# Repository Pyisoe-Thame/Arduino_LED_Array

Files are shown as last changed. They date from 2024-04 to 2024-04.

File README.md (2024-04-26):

# 8x24 LED Array, Atmega328PB

This is my PCB Design practice project. ATmega328PB is the upgraded version of ATmega328P which is no longer recommeded for new design at this time. Instead Atmega328PB is in production of microchip with more or less the same price. The distinct feature of this MCU that I noticed is it has an extra SPI protocol and some expansion on memories.

The circuit 4 74595A shift registers; one for 8 LED rows and the others for the columns.
In the circuit I used all four 595 chips have the same CLK pin connect together and 3 of them are daisy-chained to shift a total of 24 columns, the rest one is used for columns each pin cooperated
by a PNP transistor.

While it may not be able to give HIGH to all the LEDs at once, you can use time division multiplexing to achieve the same visual effect by lighting each led at multiple time slots at high frequency.

## Features

- Arudino compatible Atmega328PB-AU
- DC Jack to 5V AMS1117
- Programming with ICSP
- 74HC595A shift registers
- 24 columns, 8 rows of output LEDs

## Screenshots

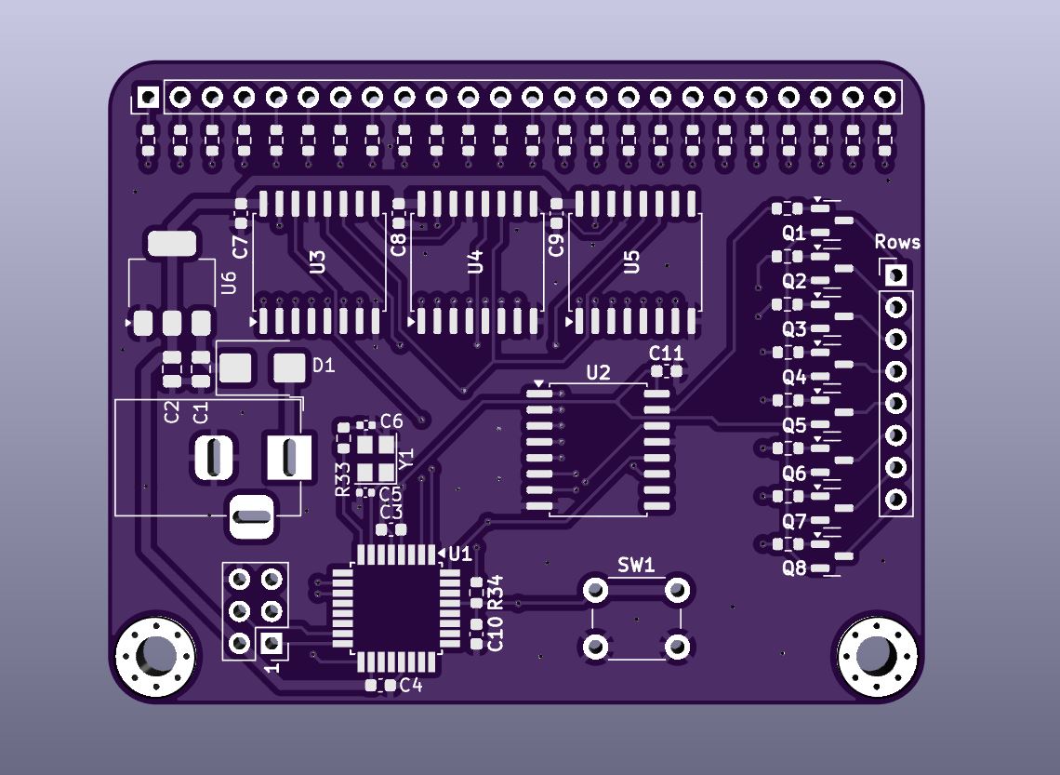
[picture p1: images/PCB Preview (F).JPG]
Front View

<p align="center">Front View</p>

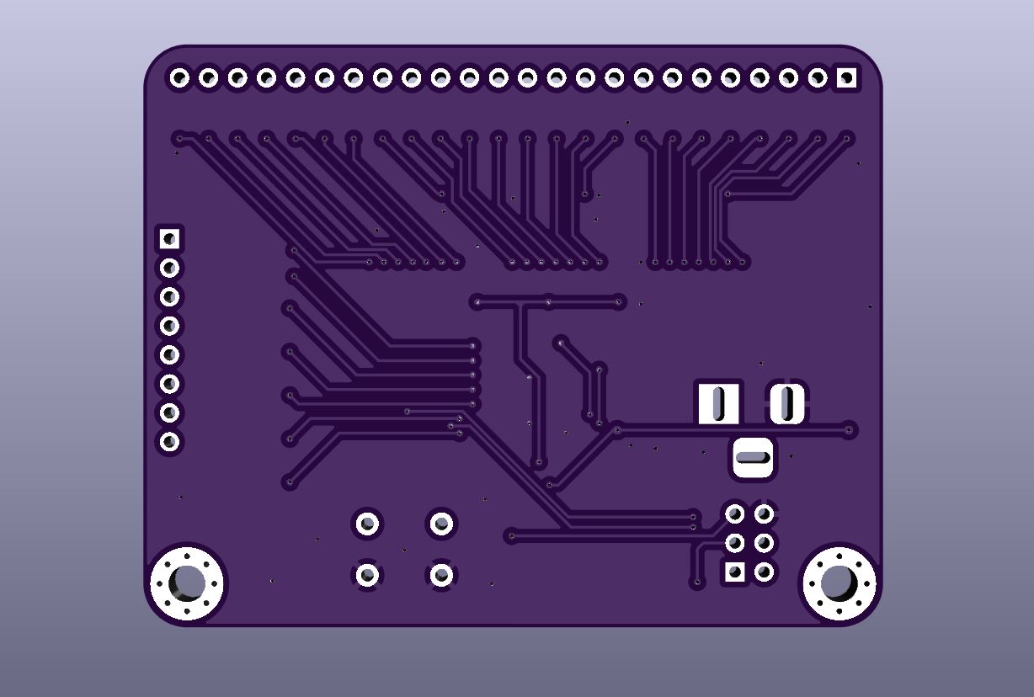
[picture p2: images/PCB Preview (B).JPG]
Back View

<p align="center">Back View</p>

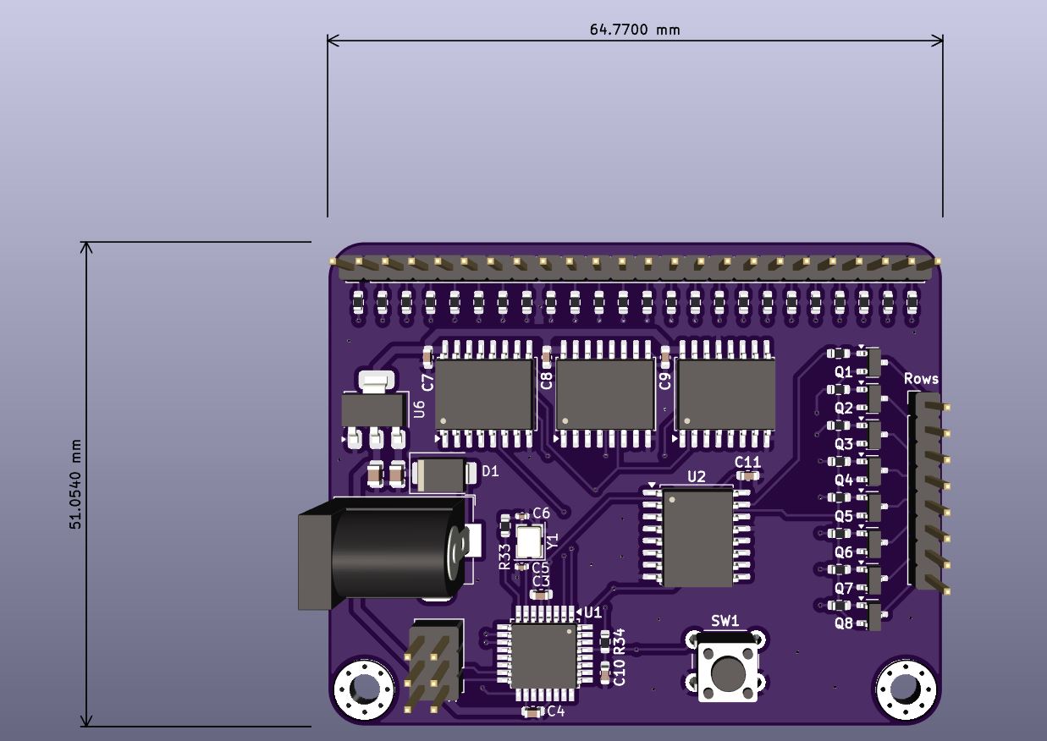
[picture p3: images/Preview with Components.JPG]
Preview with Components

<p align="center">Preview with Components</p>

## License

[MIT](https://choosealicense.com/licenses/mit/)

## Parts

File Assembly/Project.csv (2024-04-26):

Reference | Value | Datasheet | Footprint | Qty | DNP
C1,C2 | 10uF | ~ | Capacitor_SMD:C_0805_2012Metric | 2
C3,C4,C7,C8,C9,C10,C11 | 100nF | ~ | Capacitor_SMD:C_0603_1608Metric | 7
C5,C6 | 22p | ~ | Capacitor_SMD:C_0402_1005Metric | 2
D1 | M7 | https://www.tme.eu/Document/0550e9bf27627c5cdfb653945cb570ca/m1-m7.pdf | Diode_SMD:D_SMB | 1
H1,H2 | MountingHole_Pad | ~ | MountingHole:MountingHole_3.2mm_M3_Pad_Via | 2
J1 | DC Jack | ~ | Connector_BarrelJack:BarrelJack_Horizontal | 1
J2 | LED_Cols | ~ | Connector_PinHeader_2.54mm:PinHeader_1x24_P2.54mm_Vertical | 1
J3 | LED_Rows | ~ | Connector_PinHeader_2.54mm:PinHeader_1x08_P2.54mm_Vertical | 1
J4 | ICSP_Connector |  | Connector_PinHeader_2.54mm:PinHeader_2x03_P2.54mm_Vertical | 1
Q1,Q2,Q3,Q4,Q5,Q6,Q7,Q8 | BC857 | https://www.onsemi.com/pub/Collateral/BC860-D.pdf | Package_TO_SOT_SMD:SOT-23 | 8
R1,R2,R3,R4,R5,R6,R7,R8,R9,R10,R11,R12,R13,R14,R15,R16,R17,R18,R19,R20,R21,R22,R23,R24 | 220R | ~ | Resistor_SMD:R_0603_1608Metric | 24
R25,R26,R27,R28,R29,R30,R31,R32 | 100R | ~ | Resistor_SMD:R_0603_1608Metric | 8
R33 | 47R | ~ | Resistor_SMD:R_0603_1608Metric | 1
R34 | 10k | ~ | Resistor_SMD:R_0603_1608Metric | 1
SW1 | PB_6mm |  | Button_Switch_THT:SW_PUSH_6mm | 1
U1 | ATmega328PB-AU | http://ww1.microchip.com/downloads/en/DeviceDoc/40001906C.pdf | Package_QFP:TQFP-32_7x7mm_P0.8mm | 1
U2,U3,U4,U5 | 74HC595 | http://www.ti.com/lit/ds/symlink/sn74hc595.pdf | Package_SO:SOIC-16W_7.5x10.3mm_P1.27mm | 4
U6 | AMS1117-5.0 | http://www.advanced-monolithic.com/pdf/ds1117.pdf | Package_TO_SOT_SMD:SOT-223-3_TabPin2 | 1
Y1 | 16MHz | ~ | Crystal:Crystal_SMD_3225-4Pin_3.2x2.5mm | 1

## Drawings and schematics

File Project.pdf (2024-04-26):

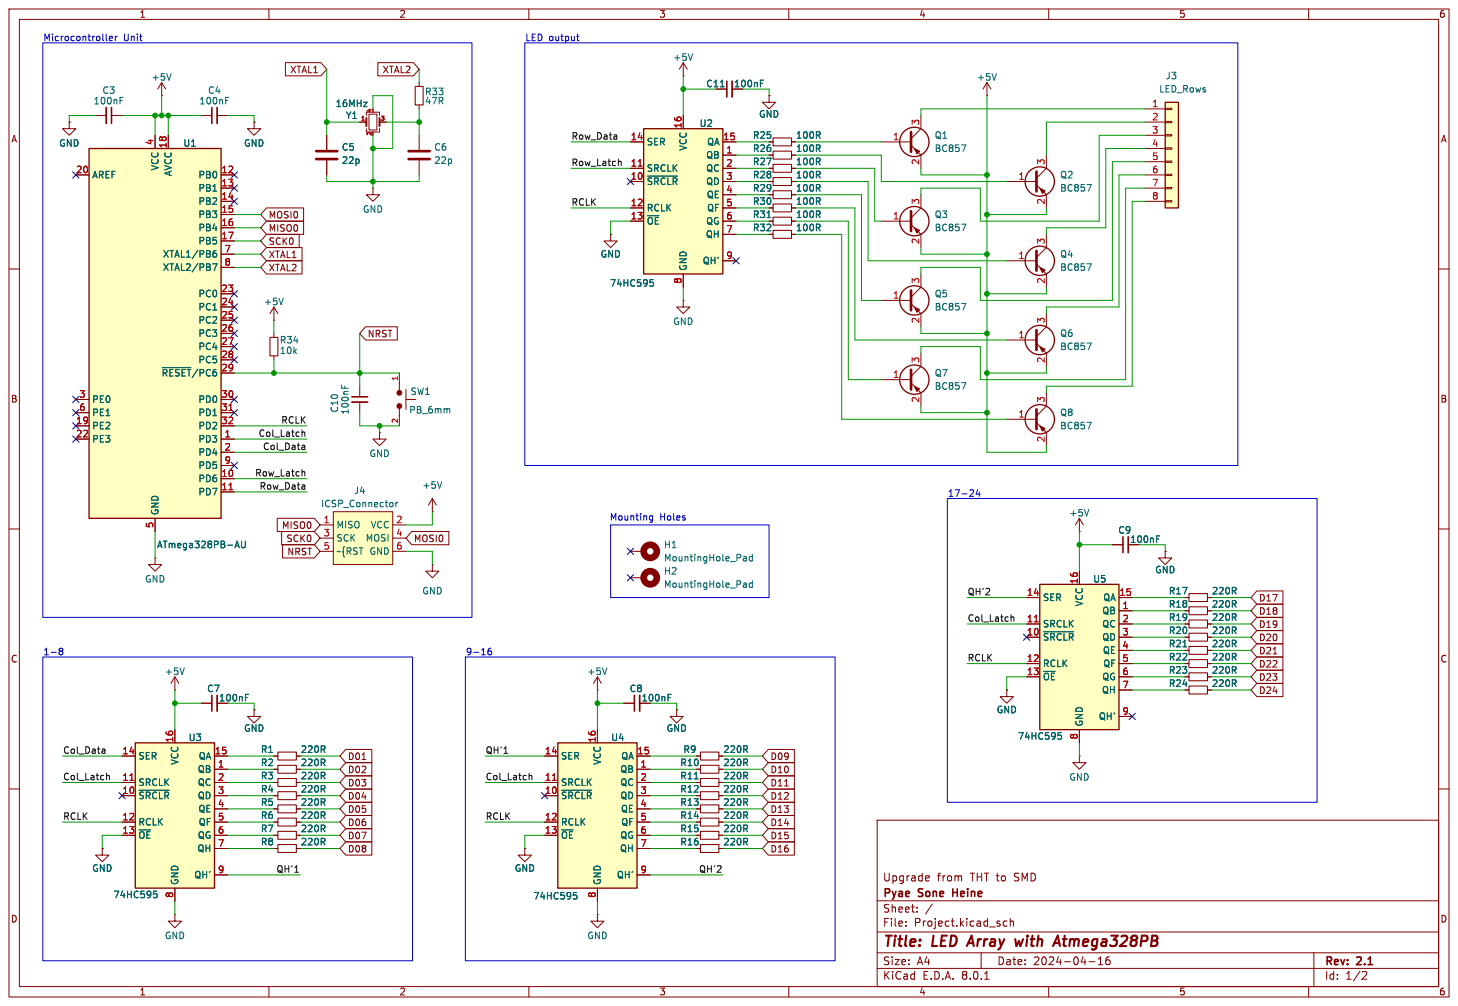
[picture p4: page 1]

Id: 1/2 Title: LED Array with Atmega328PB

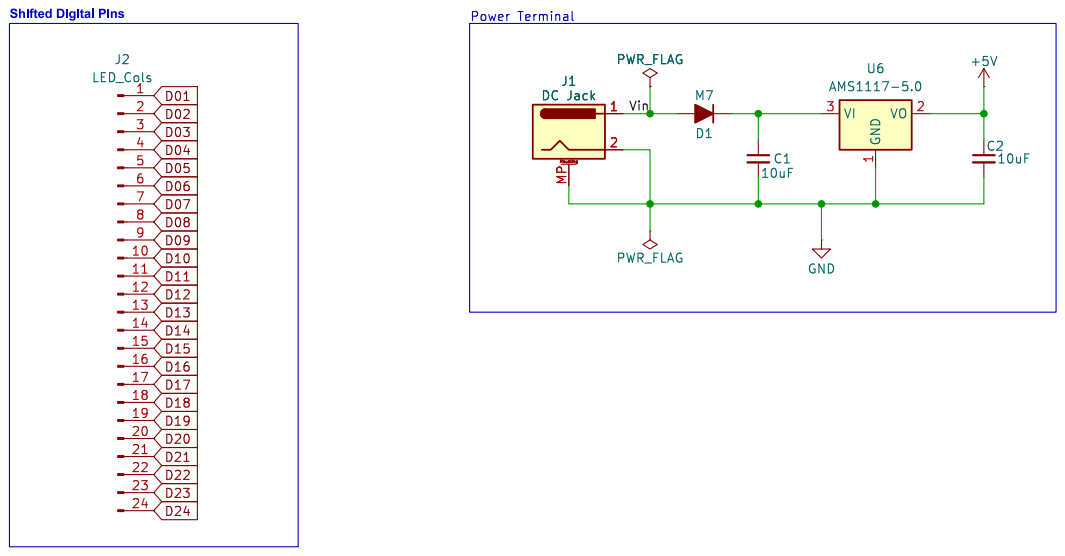
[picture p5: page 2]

Id: 2/2 Title: LED Array with Atmega328PB

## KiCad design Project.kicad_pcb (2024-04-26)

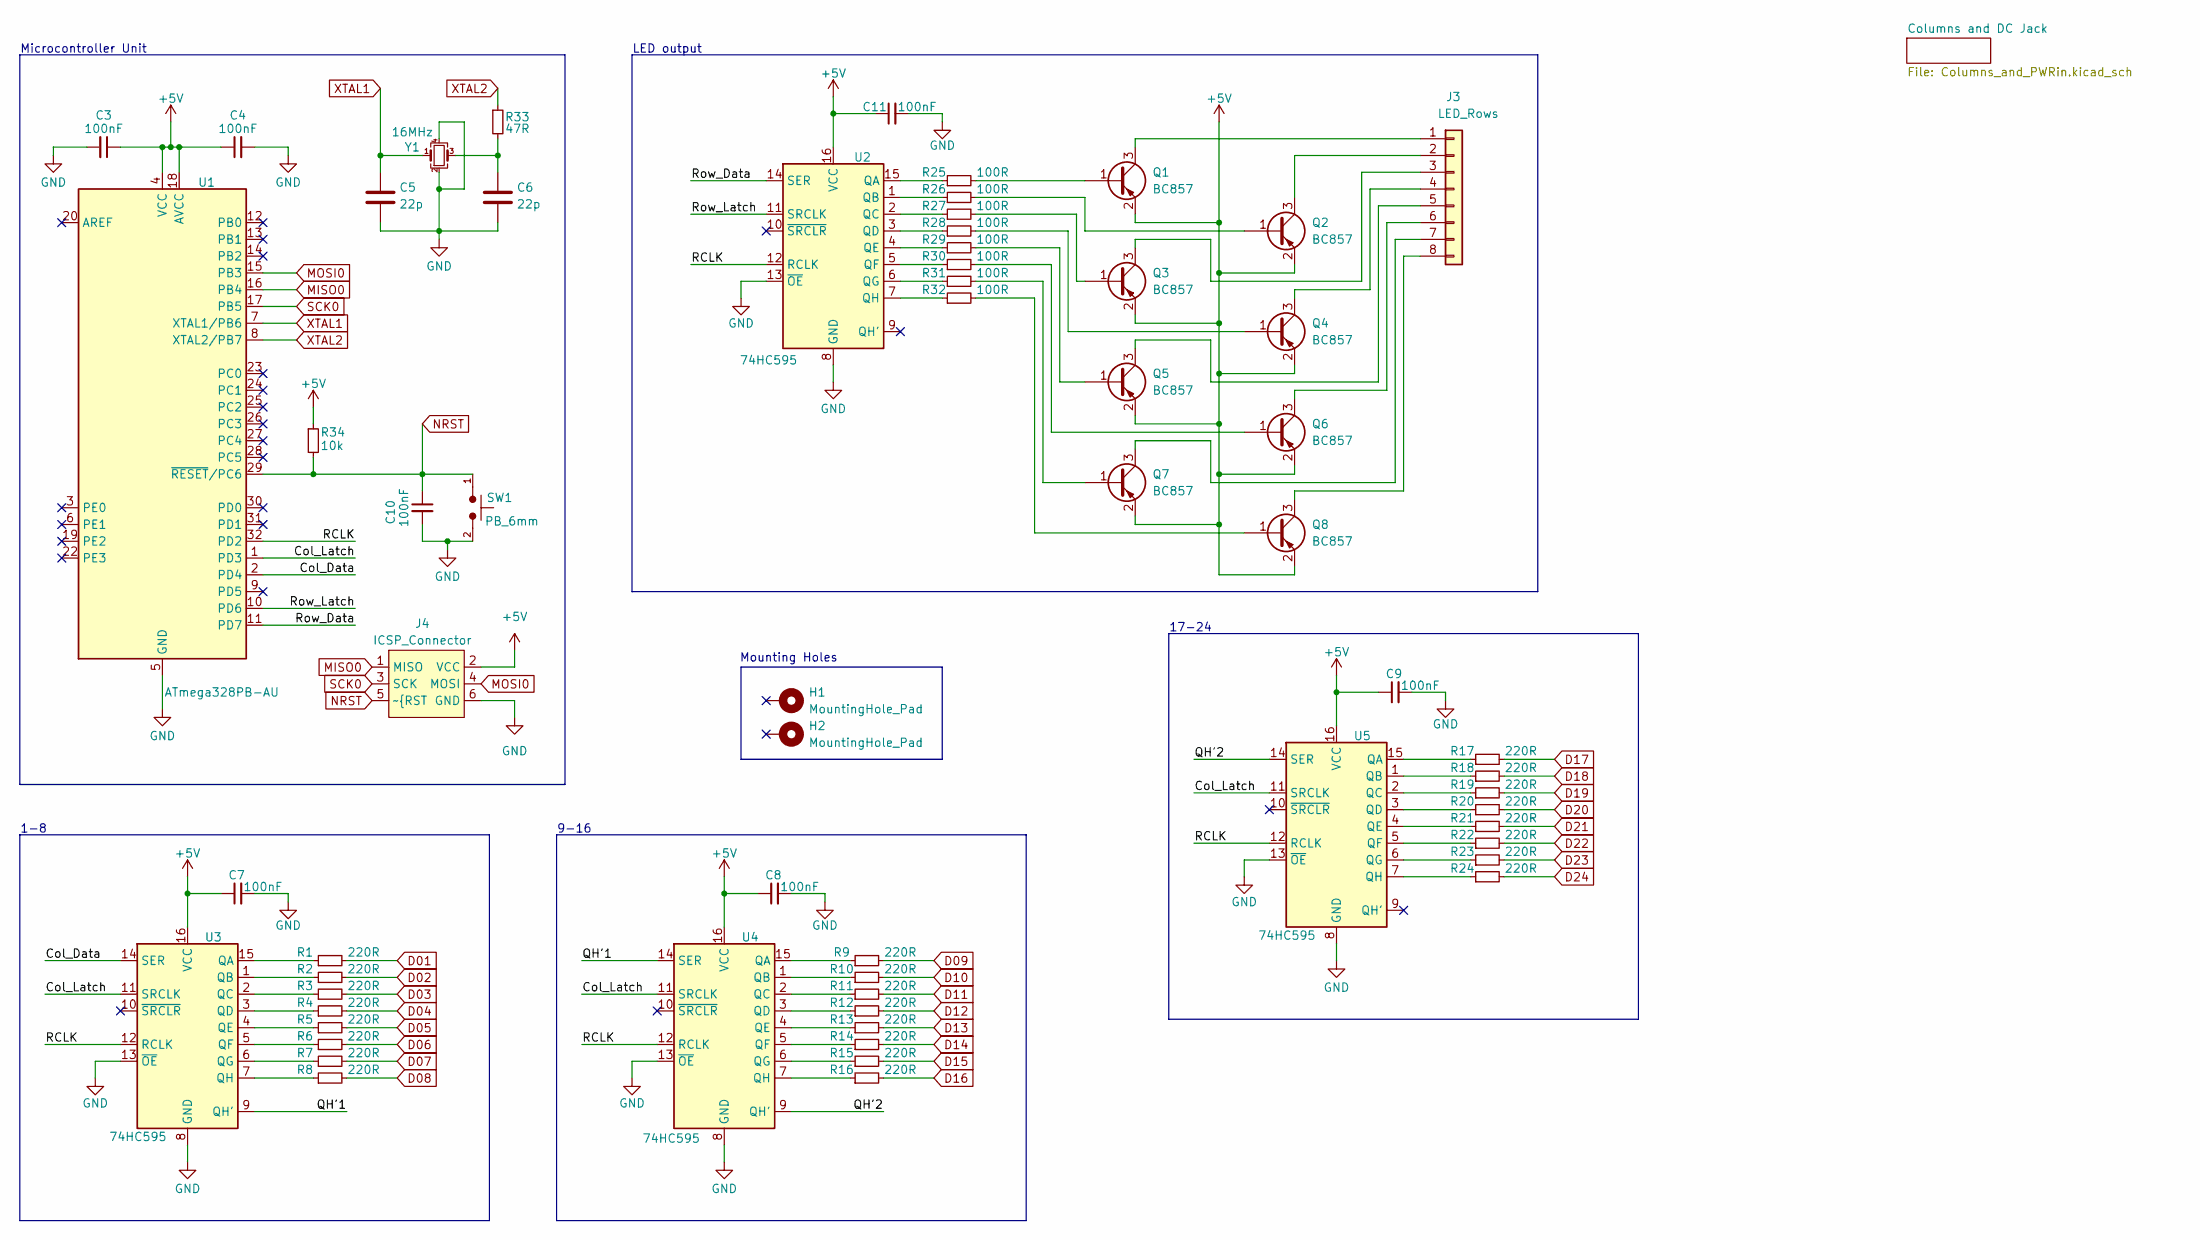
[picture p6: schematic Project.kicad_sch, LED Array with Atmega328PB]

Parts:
C3, C4, C7, C8, C9, C10, C11: 100nF; C_0603_1608Metric
C5, C6: 22p; C_0402_1005Metric
H1, H2: MountingHole_Pad; MountingHole_3.2mm_M3_Pad_Via
J3: LED_Rows; PinHeader_1x08_P2.54mm_Vertical
J4: ICSP_Connector; PinHeader_2x03_P2.54mm_Vertical
Q1, Q2, Q3, Q4, Q5, Q6, Q7, Q8: BC857; SOT-23
R1, R2, R3, R4, R5, R6, R7, R8, R9, R10, R11, R12, R13, R14, R15, R16, R17, R18, R19, R20, R21, R22, R23, R24: 220R; R_0603_1608Metric
R25, R26, R27, R28, R29, R30, R31, R32: 100R; R_0603_1608Metric
R33: 47R; R_0603_1608Metric
R34: 10k; R_0603_1608Metric
SW1: PB_6mm; SW_PUSH_6mm
U1: ATmega328PB-AU; TQFP-32_7x7mm_P0.8mm
U2, U3, U4, U5: 74HC595; SOIC-16W_7.5x10.3mm_P1.27mm
Y1: 16MHz; Crystal_SMD_3225-4Pin_3.2x2.5mm

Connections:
+5V: C3.1, C4.1, C7.1, C8.1, C9.1, C11.1, J4.2 (VCC), Q1.2 (E), Q2.2 (E), Q3.2 (E), Q4.2 (E), Q5.2 (E), Q6.2 (E), Q7.2 (E), Q8.2 (E), R34.1, U1.4 (VCC), U1.18 (AVCC), U2.16 (VCC), U3.16 (VCC), U4.16 (VCC), U5.16 (VCC); also elsewhere on the board
/Col_Data: U1.2 (PD4), U3.14 (SER)
/Col_Latch: U1.1 (PD3), U3.11 (SRCLK), U4.11 (SRCLK), U5.11 (SRCLK)
/QH'1: U3.9 (QH'), U4.14 (SER)
/QH'2: U4.9 (QH'), U5.14 (SER)
/RCLK: U1.32 (PD2), U2.12 (RCLK), U3.12 (RCLK), U4.12 (RCLK), U5.12 (RCLK)
/Row_Data: U1.11 (PD7), U2.14 (SER)
/Row_Latch: U1.10 (PD6), U2.11 (SRCLK)
D01: R1.2; also elsewhere on the board
D02: R2.2; also elsewhere on the board
D03: R3.2; also elsewhere on the board
D04: R4.2; also elsewhere on the board
D05: R5.2; also elsewhere on the board
D06: R6.2; also elsewhere on the board
D07: R7.2; also elsewhere on the board
D08: R8.2; also elsewhere on the board
D09: R9.2; also elsewhere on the board
D10: R10.2; also elsewhere on the board
D11: R11.2; also elsewhere on the board
D12: R12.2; also elsewhere on the board
D13: R13.2; also elsewhere on the board
D14: R14.2; also elsewhere on the board
D15: R15.2; also elsewhere on the board
D16: R16.2; also elsewhere on the board
D17: R17.2; also elsewhere on the board
D18: R18.2; also elsewhere on the board
D19: R19.2; also elsewhere on the board
D20: R20.2; also elsewhere on the board
D21: R21.2; also elsewhere on the board
D22: R22.2; also elsewhere on the board
D23: R23.2; also elsewhere on the board
D24: R24.2; also elsewhere on the board
GND: C3.2, C4.2, C5.2, C6.2, C7.2, C8.2, C9.2, C10.2, C11.2, J4.6 (GND), SW1.2, U1.5 (GND), U1.21 (GND), U2.8 (GND), U2.13 (~OE), U3.8 (GND), U3.13 (~OE), U4.8 (GND), U4.13 (~OE), U5.8 (GND), U5.13 (~OE), Y1.2, Y1.4; also elsewhere on the board
MISO0: J4.1 (MISO), U1.16 (PB4)
MOSI0: J4.4 (MOSI), U1.15 (PB3)
NRST: C10.1, J4.5 (~{RST), R34.2, SW1.1, U1.29 (~RESET/PC6)
unnamed: C6.1, R33.2, Y1.3
unnamed: J3.1, Q1.3 (C)
unnamed: J3.2, Q2.3 (C)
unnamed: J3.3, Q3.3 (C)
unnamed: J3.4, Q4.3 (C)
unnamed: J3.5, Q5.3 (C)
unnamed: J3.6, Q6.3 (C)
unnamed: J3.7, Q7.3 (C)
unnamed: J3.8, Q8.3 (C)
unnamed: Q1.1 (B), R25.2
unnamed: Q2.1 (B), R26.2
unnamed: Q3.1 (B), R27.2
unnamed: Q4.1 (B), R28.2
unnamed: Q5.1 (B), R29.2
unnamed: Q6.1 (B), R30.2
unnamed: Q7.1 (B), R31.2
unnamed: Q8.1 (B), R32.2
unnamed: R25.1, U2.15 (QA)
unnamed: R26.1, U2.1 (QB)
unnamed: R27.1, U2.2 (QC)
unnamed: R28.1, U2.3 (QD)
unnamed: R29.1, U2.4 (QE)
unnamed: R30.1, U2.5 (QF)
unnamed: R31.1, U2.6 (QG)
unnamed: R32.1, U2.7 (QH)
unnamed: R1.1, U3.15 (QA)
unnamed: R2.1, U3.1 (QB)
unnamed: R3.1, U3.2 (QC)
unnamed: R4.1, U3.3 (QD)
unnamed: R5.1, U3.4 (QE)
unnamed: R6.1, U3.5 (QF)
unnamed: R7.1, U3.6 (QG)
unnamed: R8.1, U3.7 (QH)
unnamed: R9.1, U4.15 (QA)
unnamed: R10.1, U4.1 (QB)
unnamed: R11.1, U4.2 (QC)
unnamed: R12.1, U4.3 (QD)
unnamed: R13.1, U4.4 (QE)
unnamed: R14.1, U4.5 (QF)
unnamed: R15.1, U4.6 (QG)
unnamed: R16.1, U4.7 (QH)
unnamed: R17.1, U5.15 (QA)
unnamed: R18.1, U5.1 (QB)
unnamed: R19.1, U5.2 (QC)
unnamed: R20.1, U5.3 (QD)
unnamed: R21.1, U5.4 (QE)
unnamed: R22.1, U5.5 (QF)
unnamed: R23.1, U5.6 (QG)
unnamed: R24.1, U5.7 (QH)
SCK0: J4.3 (SCK), U1.17 (PB5)
XTAL1: C5.1, U1.7 (XTAL1/PB6), Y1.1
XTAL2: R33.1, U1.8 (XTAL2/PB7)

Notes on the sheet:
1-8
17-24
Mounting Holes
9-16
Microcontroller Unit
LED output

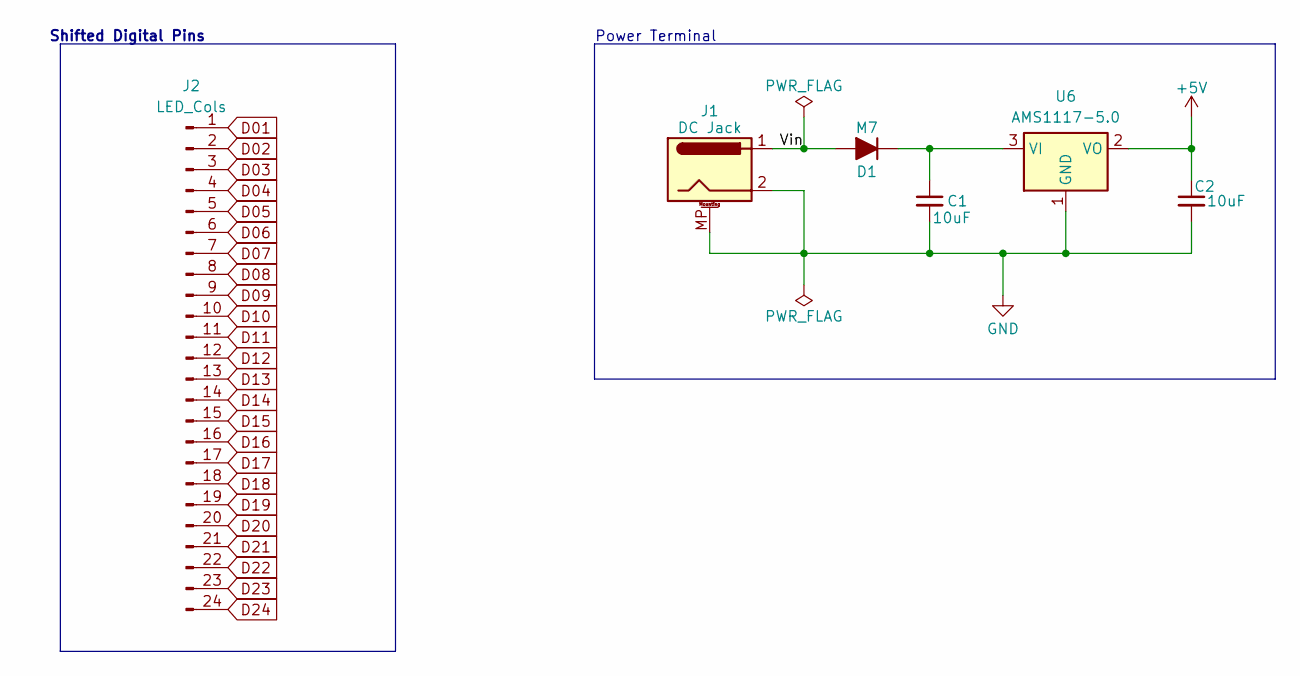
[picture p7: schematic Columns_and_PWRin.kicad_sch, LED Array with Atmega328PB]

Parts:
C1, C2: 10uF; C_0805_2012Metric
D1: M7; D_SMB
J1: DC Jack; BarrelJack_Horizontal
J2: LED_Cols; PinHeader_1x24_P2.54mm_Vertical
U6: AMS1117-5.0; SOT-223-3_TabPin2

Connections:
+5V: C2.1, U6.2 (VO); also elsewhere on the board
/Columns and DC Jack/Vin: D1.2 (A), J1.1
D01: J2.1; also elsewhere on the board
D02: J2.2; also elsewhere on the board
D03: J2.3; also elsewhere on the board
D04: J2.4; also elsewhere on the board
D05: J2.5; also elsewhere on the board
D06: J2.6; also elsewhere on the board
D07: J2.7; also elsewhere on the board
D08: J2.8; also elsewhere on the board
D09: J2.9; also elsewhere on the board
D10: J2.10; also elsewhere on the board
D11: J2.11; also elsewhere on the board
D12: J2.12; also elsewhere on the board
D13: J2.13; also elsewhere on the board
D14: J2.14; also elsewhere on the board
D15: J2.15; also elsewhere on the board
D16: J2.16; also elsewhere on the board
D17: J2.17; also elsewhere on the board
D18: J2.18; also elsewhere on the board
D19: J2.19; also elsewhere on the board
D20: J2.20; also elsewhere on the board
D21: J2.21; also elsewhere on the board
D22: J2.22; also elsewhere on the board
D23: J2.23; also elsewhere on the board
D24: J2.24; also elsewhere on the board
GND: C1.2, C2.2, J1.2, J1.MP (MountPin), U6.1 (GND); also elsewhere on the board
unnamed: C1.1, D1.1 (K), U6.3 (VI)

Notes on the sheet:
Power Terminal
Shifted Digital Pins

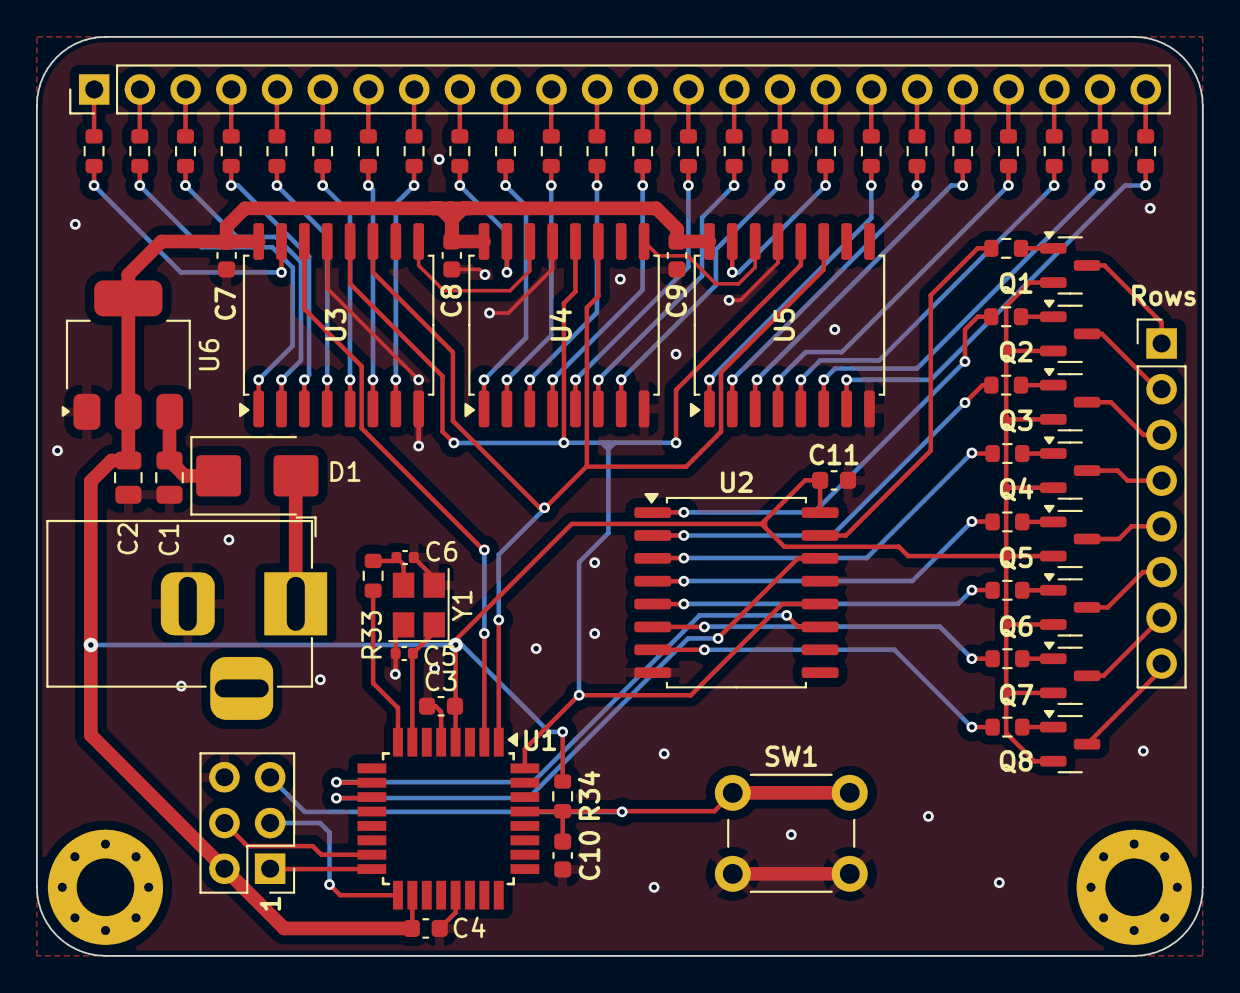
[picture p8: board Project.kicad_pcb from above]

Board: 2 copper layers, 64.8 x 51.1 mm, 68 parts (0 on the bottom side), 90 nets.

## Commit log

2024-04-16 PCB design done, BOM still undecided
    [Columns_and_PWRin.kicad_sch, Project.kicad_pcb, Project.kicad_sch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]
2024-04-26 595 column chip not daisy chained and floating OE pins mistakes corrected
    [Project-B_Courtyard.gbr, Project-B_Cu.gbr, Project-B_Fab.gbr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]
2024-04-26 Rename PCB Preview (F).JPG to PCB Preview.JPG
    Fixing Wrong image name
2024-04-26 Rename PCB Preview (B).JPG to PCB Preview (F).JPG
    Correcting wrong name
2024-04-26 Rename PCB Preview.JPG to PCB Preview (B).JPG
    Change the name
